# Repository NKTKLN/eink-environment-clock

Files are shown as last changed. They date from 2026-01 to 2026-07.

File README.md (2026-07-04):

# 🖥️ E-Ink Environment Clock





**eink-environment-clock** is a minimal ESP32-C3 based E-Ink desk clock that displays time and indoor air data.
It combines a low-power E-Ink screen with CO₂, temperature, humidity, and pressure sensing, making it useful as both a clock and a compact environment monitor.

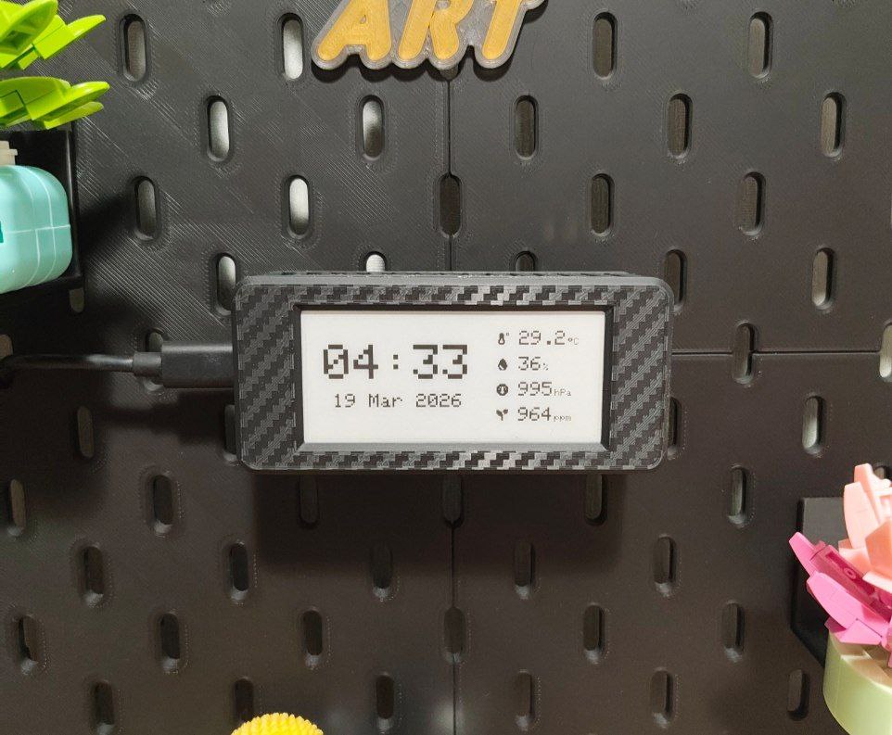
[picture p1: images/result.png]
Result


## 🧩 PCB

PCB design and assembly are illustrated with the following reference images:

```bash
images/
├── assembled_board_image.png
├── circuit_image.png
├── pcb_back_image.png
├── pcb_front_image.png
└── schematic_image.png
```

### Circuit

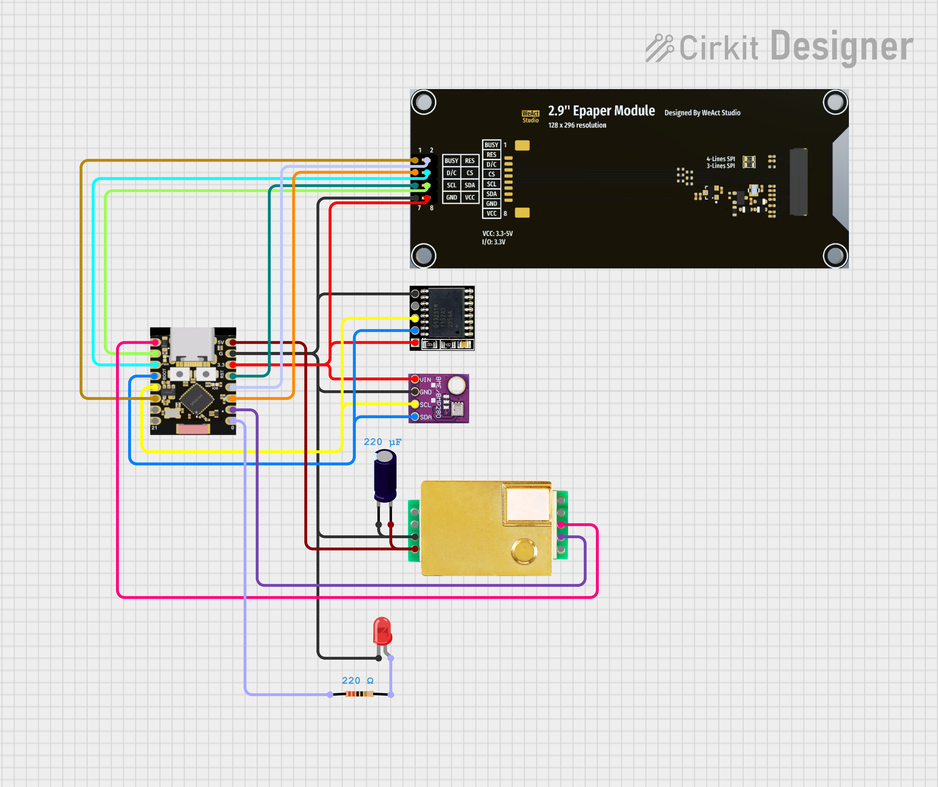
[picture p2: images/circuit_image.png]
Circuit


## 💾 Firmware

The firmware is a pure **ESP-IDF** PlatformIO project (no Arduino) located in:

```bash
firmware/
├── platformio.ini
└── src/
    ├── app_main.c        # application logic
    ├── app_config.h      # pins, Wi-Fi credentials, timings
    ├── secrets.h.example # Wi-Fi credentials template (copy to secrets.h)
    ├── epd_ssd1680.*     # e-paper driver (WeAct 2.9" B/W, SSD1680)
    ├── epd_canvas.*      # 1bpp canvas, bitmap fonts, icons
    ├── ui.*              # clock face rendering
    └── net_time.*        # Wi-Fi + SNTP time sync
```

Before building, set up your Wi-Fi credentials (only needed if `USE_WIFI_TIME_SYNC` is enabled in `app_config.h`):

```bash
cp firmware/src/secrets.h.example firmware/src/secrets.h
# then edit secrets.h with your WIFI_SSID / WIFI_PASSWORD
```

Build and flash (ESP32-C3 Super Mini over native USB):

```bash
cd firmware
pio run -t upload && pio device monitor
```

## 📚 Libraries

Sensors are handled by [esp-idf-lib](https://esp-idf-lib.readthedocs.io/) components (fetched automatically from the ESP Component Registry):

* **bmp280** — BME280 temperature / humidity / pressure
* **ds3231** — RTC
* **mhz19b** — CO₂ sensor

The e-paper driver is custom and follows the panel vendor's reference code from [WeActStudio.EpaperModule](https://github.com/WeActStudio/WeActStudio.EpaperModule).

## 📦 Case

The case model for this project is located in:

```bash
3d_model/
├── stp
│   ├── backplate.stp
│   ├── center.stp
│   └── frontplate.stp
├── case.3mf
└── case.m3d
```

## ⚠️ Known Issues

* Holes for the **MH-Z19** are too small.
* Some modules (**MH-Z19**) are placed too close to the mounting holes, which sometimes makes assembly and fastening inconvenient.

## 📜 License

This project is licensed under the MIT License. See the [LICENSE](./LICENSE) file for details.

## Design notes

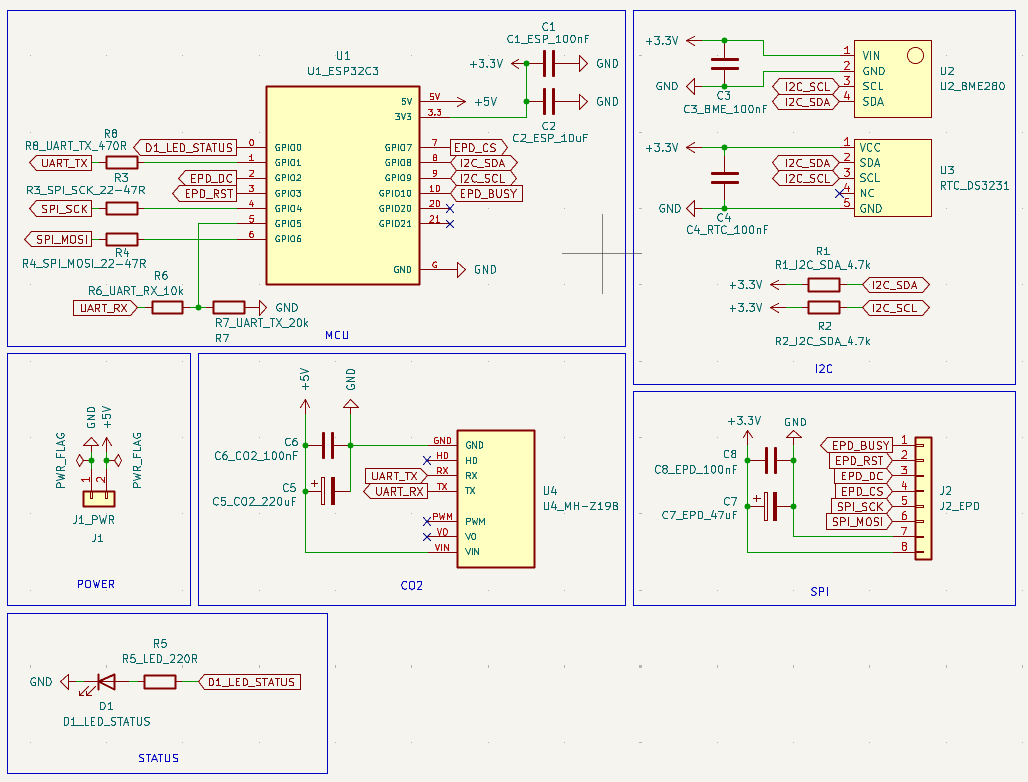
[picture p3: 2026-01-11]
images/schematic_image.png

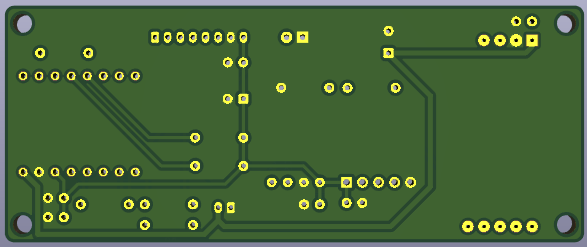
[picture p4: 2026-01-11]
images/pcb_back_image.png

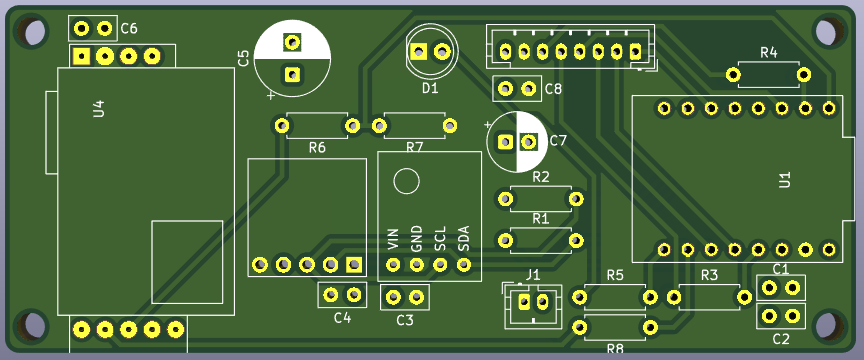
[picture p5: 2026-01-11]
images/pcb_front_image.png

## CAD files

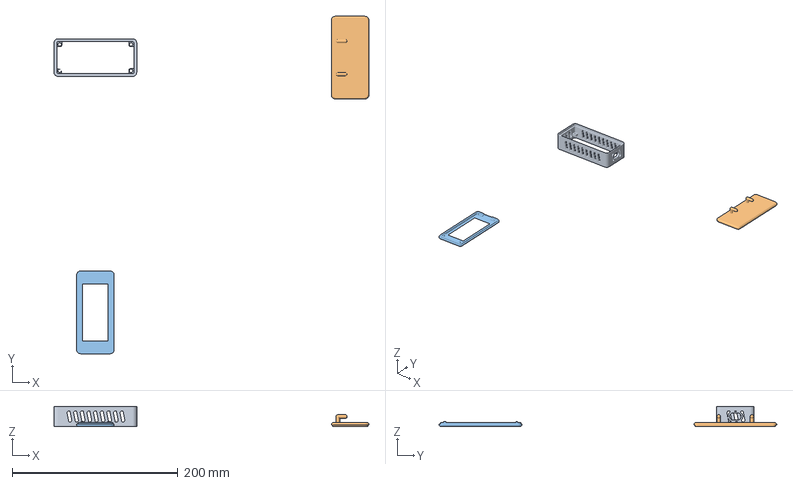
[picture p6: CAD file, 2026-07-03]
3d_model/case.3mf
379.9 x 407.0 x 24.6 mm
frontplate.stp

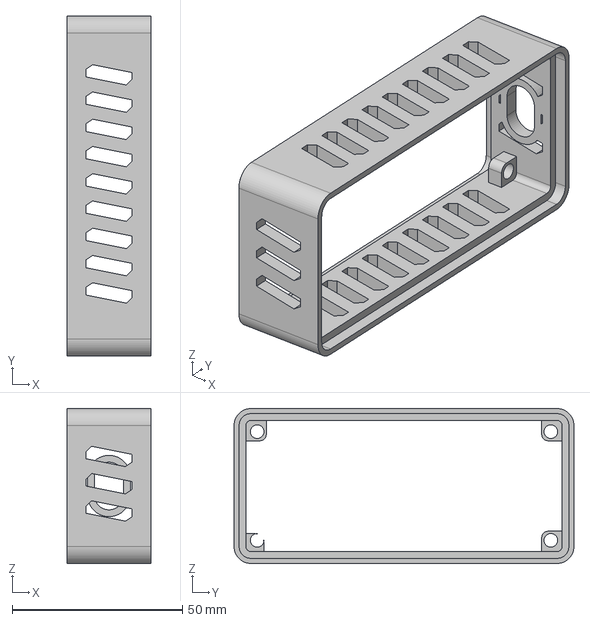
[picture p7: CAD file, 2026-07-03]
3d_model/stp/center.stp
24.6 x 99.8 x 45.5 mm

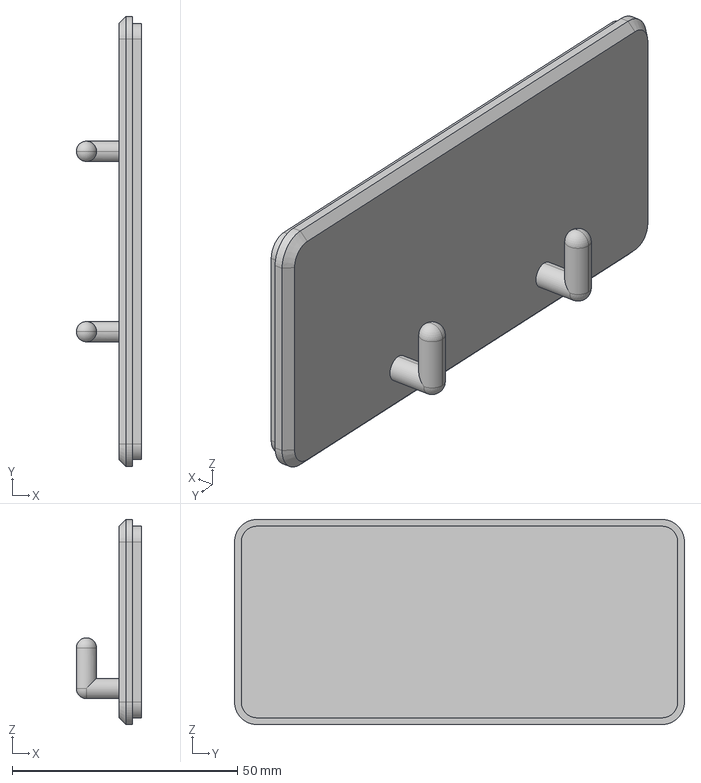
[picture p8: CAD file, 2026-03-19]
3d_model/stp/backplate.stp
14.5 x 99.8 x 45.5 mm

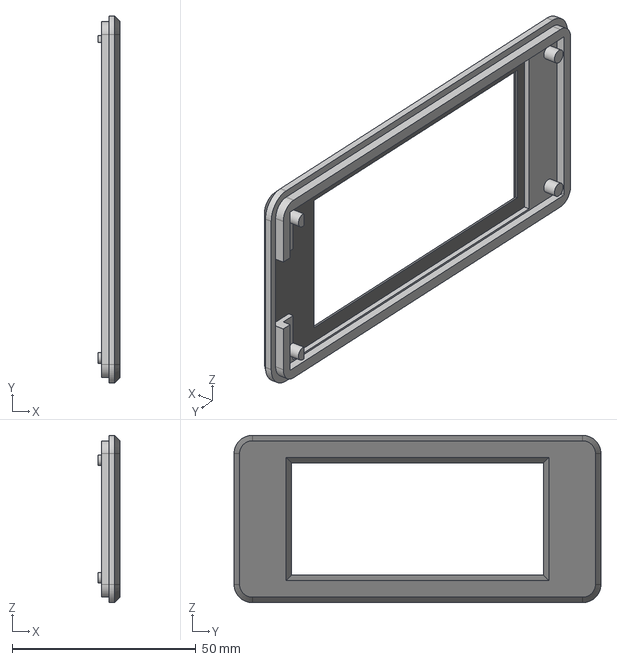
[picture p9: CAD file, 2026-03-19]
3d_model/stp/frontplate.stp
6.00 x 99.8 x 45.5 mm

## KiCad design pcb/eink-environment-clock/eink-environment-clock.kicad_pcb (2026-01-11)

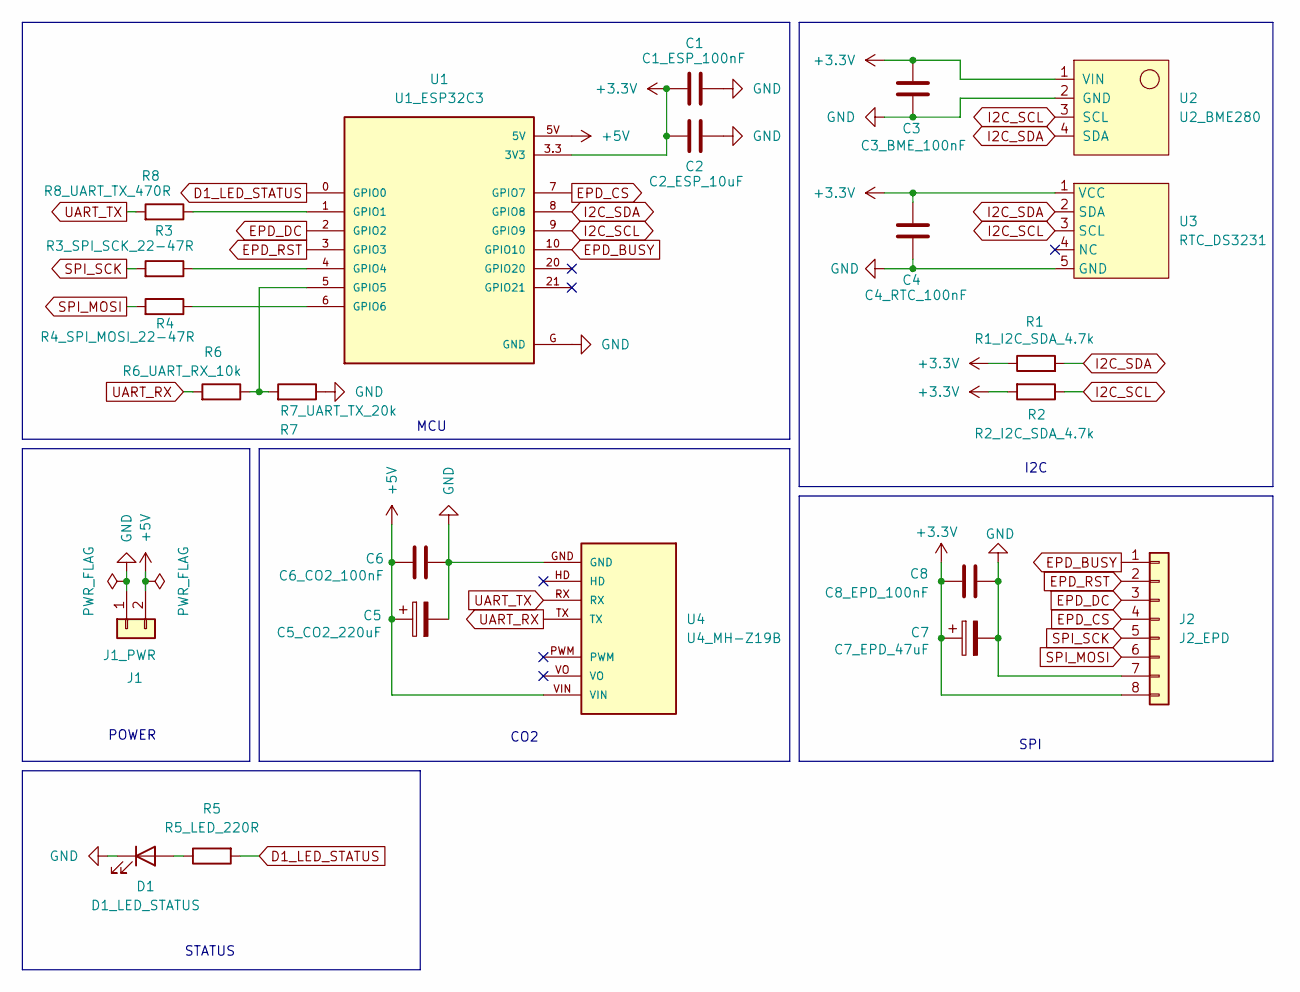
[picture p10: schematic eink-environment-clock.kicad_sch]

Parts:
C1: C1_ESP_100nF; C_Disc_D5.0mm_W2.5mm_P2.50mm
C2: C2_ESP_10uF; C_Disc_D5.0mm_W2.5mm_P2.50mm
C3: C3_BME_100nF; C_Disc_D5.0mm_W2.5mm_P2.50mm
C4: C4_RTC_100nF; C_Disc_D5.0mm_W2.5mm_P2.50mm
C5: C5_CO2_220uF; CP_Radial_D8.0mm_P3.50mm
C6: C6_CO2_100nF; C_Disc_D5.0mm_W2.5mm_P2.50mm
C7: C7_EPD_47uF; CP_Radial_D6.3mm_P2.50mm
C8: C8_EPD_100nF; C_Disc_D5.0mm_W2.5mm_P2.50mm
D1: D1_LED_STATUS; LED_D5.0mm
J1: J1_PWR; JST_PH_B2B-PH-K_1x02_P2.00mm_Vertical
J2: J2_EPD; JST_PH_B8B-PH-K_1x08_P2.00mm_Vertical
R1: R1_I2C_SDA_4.7k; R_Axial_DIN0207_L6.3mm_D2.5mm_P7.62mm_Horizontal
R2: R2_I2C_SDA_4.7k; R_Axial_DIN0207_L6.3mm_D2.5mm_P7.62mm_Horizontal
R3: R3_SPI_SCK_22-47R; R_Axial_DIN0207_L6.3mm_D2.5mm_P7.62mm_Horizontal
R4: R4_SPI_MOSI_22-47R; R_Axial_DIN0207_L6.3mm_D2.5mm_P7.62mm_Horizontal
R5: R5_LED_220R; R_Axial_DIN0207_L6.3mm_D2.5mm_P7.62mm_Horizontal
R6: R6_UART_RX_10k; R_Axial_DIN0207_L6.3mm_D2.5mm_P7.62mm_Horizontal
R7: R7_UART_TX_20k; R_Axial_DIN0207_L6.3mm_D2.5mm_P7.62mm_Horizontal
R8: R8_UART_TX_470R; R_Axial_DIN0207_L6.3mm_D2.5mm_P7.62mm_Horizontal
U1: U1_ESP32C3; MODULE_ESP32-C3_SUPERMINI_TH
U2: U2_BME280; module_bme280_alt
U3: RTC_DS3231; DS3231_For_Pi
U4: U4_MH-Z19B; MH-Z19B

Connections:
+3.3V: C1.2, C2.2, C3.1, C4.1, C7.1, C8.2, J2.8, R1.1, R2.2, U1.3.3 (3V3), U2.1 (VIN), U3.1 (VCC)
+5V: C5.1, C6.2, J1.2, U1.5V, U4.VIN
D1_LED_STATUS: R5.2, U1.0 (GPIO0)
EPD_BUSY: J2.1, U1.10 (GPIO10)
EPD_CS: J2.4, U1.7 (GPIO7)
EPD_DC: J2.3, U1.2 (GPIO2)
EPD_RST: J2.2, U1.3 (GPIO3)
GND: C1.1, C2.1, C3.2, C4.2, C5.2, C6.1, C7.2, C8.1, D1.1 (K), J1.1, J2.7, R7.1, U1.G (GND), U2.2 (GND), U3.5 (GND), U4.GND
I2C_SCL: R2.1, U1.9 (GPIO9), U2.3 (SCL), U3.3 (SCL)
I2C_SDA: R1.2, U1.8 (GPIO8), U2.4 (SDA), U3.2 (SDA)
unnamed: D1.2 (A), R5.1
unnamed: R8.1, U1.1 (GPIO1)
unnamed: R3.1, U1.4 (GPIO4)
unnamed: R6.1, R7.2, U1.5 (GPIO5)
unnamed: R4.1, U1.6 (GPIO6)
SPI_MOSI: J2.6, R4.2
SPI_SCK: J2.5, R3.2
UART_RX: R6.2, U4.TX
UART_TX: R8.2, U4.RX

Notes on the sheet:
POWER
CO2
SPI
I2C
STATUS
MCU

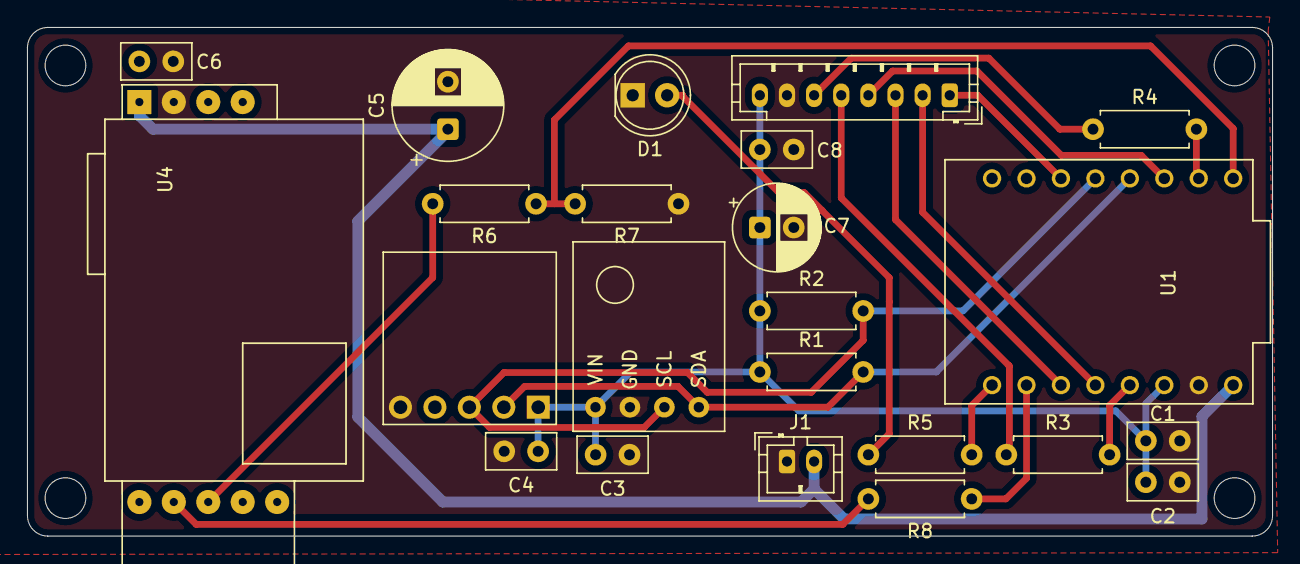
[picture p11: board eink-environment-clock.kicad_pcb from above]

Board: 2 copper layers, 91.8 x 37.5 mm, 23 parts (0 on the bottom side), 19 nets.

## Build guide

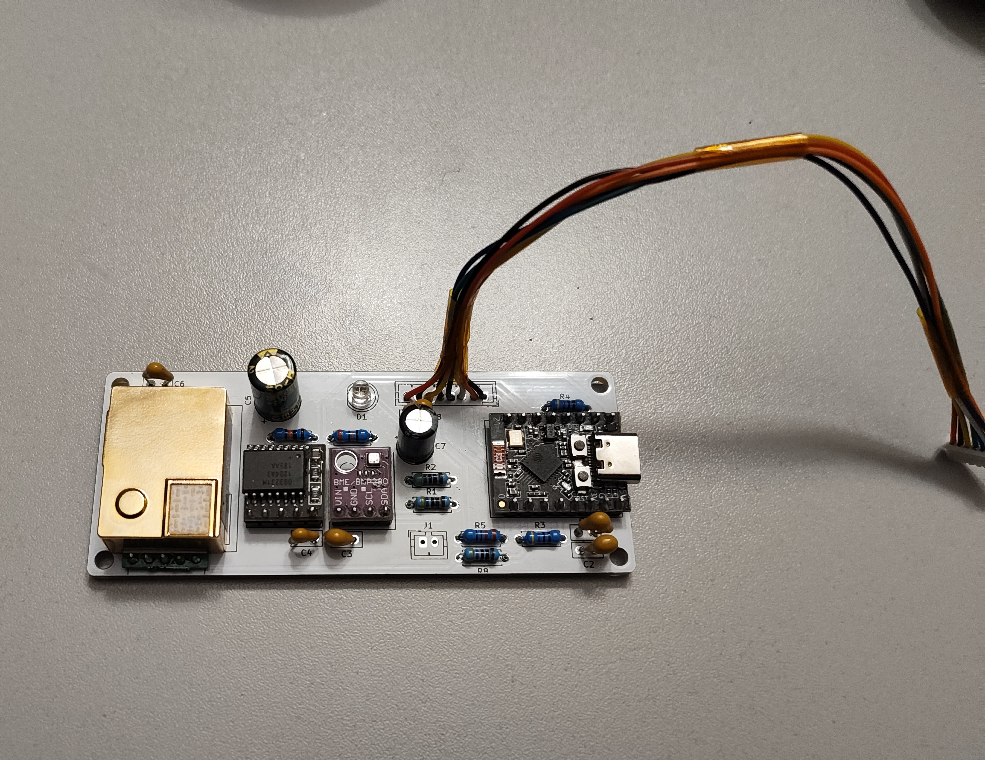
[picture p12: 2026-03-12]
images/assembled_board_image.png

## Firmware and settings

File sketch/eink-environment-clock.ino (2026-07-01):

#include <SPI.h>
#include <GxEPD2_BW.h>
#include <Adafruit_GFX.h>

#include <math.h>
#include <WiFi.h>
#include <Wire.h>
#include <Adafruit_BME280.h>
#include <RTClib.h>
#include <time.h>
#include <MHZ19.h>

// =====================================================
// Pin configuration
// =====================================================

// E-paper display pins
constexpr uint8_t PIN_EPD_DC   = 2;
constexpr uint8_t PIN_EPD_RST  = 3;
constexpr uint8_t PIN_SPI_SCK  = 4;
constexpr uint8_t PIN_SPI_MOSI = 6;
constexpr uint8_t PIN_EPD_CS   = 7;
constexpr uint8_t PIN_EPD_BUSY = 10;

// I2C pins
constexpr uint8_t I2C_SDA_PIN = 8;
constexpr uint8_t I2C_SCL_PIN = 9;

// MH-Z19 UART pins
constexpr uint8_t MHZ_RX_PIN = 5;
constexpr uint8_t MHZ_TX_PIN = 1;

// Status LED pin
constexpr uint8_t LED_PIN = 0;

// =====================================================
// Application configuration
// =====================================================

// Time format
constexpr bool USE_12_HOUR_FORMAT = true;

// Time synchronization
constexpr bool USE_WIFI_TIME_SYNC = true;

// Wi-Fi credentials
constexpr char WIFI_SSID[] = "YourWiFiName";
constexpr char WIFI_PASSWORD[] = "YourWiFiPassword";

// NTP settings
constexpr char NTP_SERVER[] = "pool.ntp.org";
constexpr char TIME_ZONE[]  = "MSK-3";

// BME280 settings
constexpr uint8_t BME280_ADDRESS_PRIMARY   = 0x76;
constexpr uint8_t BME280_ADDRESS_SECONDARY = 0x77;
constexpr float BME280_TEMP_OFFSET_C = -2.3f;

// MZH19b settings
constexpr int CO2_ALERT_THRESHOLD_PPM = 1000;  // Blink the status LED when CO2 exceeds this level

// Screen settings
constexpr bool USE_DARK_THEME = false; // true - not recommended
constexpr bool SKIP_UPDATE_IF_DATA_UNCHANGED = true;

// =====================================================
// Timing configuration
// =====================================================

constexpr uint32_t SENSOR_UPDATE_INTERVAL_MS           = 30000;    // Read sensors every 30 seconds
constexpr uint32_t DISPLAY_UPDATE_INTERVAL_MS          = 1000;     // Update display every second
constexpr uint16_t DISPLAY_FULL_REFRESH_EVERY          = 30;       // Full refresh every N partial updates (clears ghosting)
constexpr uint32_t WIFI_TIME_SYNC_INTERVAL_MS          = 1800000;  // Sync time every 30 minutes
constexpr uint32_t WIFI_CONNECT_TIMEOUT_MS             = 15000;    // Wi-Fi connection timeout
constexpr uint32_t NTP_SYNC_TIMEOUT_MS                 = 15000;    // NTP synchronization timeout
constexpr uint32_t LED_BLINK_INTERVAL_MS               = 1000;     // LED blink interval when CO2 is above the alert threshold

// =====================================================
// Timing state
// =====================================================

uint32_t lastSensorUpdateMs  = 0;
uint32_t lastDisplayUpdateMs = 0;
uint32_t lastTimeSyncMs      = 0;
uint32_t lastLedToggleMs     = 0;

// =====================================================
// Counters
// =====================================================

uint16_t updatesSinceFullRefresh = 0;

// =====================================================
// Runtime flags
// =====================================================

bool wifiConnected     = false;
bool firstDisplayDraw  = true;
bool bme280Available   = false;
bool ds3231Available   = false;
bool mhz19Available    = false;
bool displayAvailable  = false;
bool ledOn             = false;
bool sensorDataChanged = false;
bool timeChanged       = false;

// =====================================================
// Global objects
// =====================================================

// E-paper display driver
GxEPD2_BW<GxEPD2_290_T94_V2, GxEPD2_290_T94_V2::HEIGHT> display(
  GxEPD2_290_T94_V2(PIN_EPD_CS, PIN_EPD_DC, PIN_EPD_RST, PIN_EPD_BUSY)
);

// Peripherals
Adafruit_BME280 bme;
RTC_DS3231 rtc;
MHZ19 mhz19;
HardwareSerial mhzSerial(1);

// =====================================================
// Sensor & time data
// =====================================================

struct SensorData {
  float temperatureC = NAN;
  float humidityPct  = NAN;
  float pressureHpa  = NAN;
  int   co2Ppm       = -1;
};

SensorData lastSensorData;
DateTime lastRtcTime;

// =====================================================
// Bitmap icons
// =====================================================

// 16x16 humidity icon
const unsigned char ICON_DROPLET_16X16[] PROGMEM = {
  0x00, 0x00, 0x00, 0x00, 0x80, 0x01, 0xc0, 0x03, 0xe0, 0x07, 0xe0, 0x07,
  0xf0, 0x0f, 0xf0, 0x0f, 0xf8, 0x1f, 0xd8, 0x1f, 0x98, 0x1f, 0x30, 0x0f,
  0x70, 0x0e, 0xe0, 0x07, 0x00, 0x00, 0x00, 0x00
};

// 16x16 pressure icon
const unsigned char ICON_GAUGE_16X16[] PROGMEM = {
  0x00, 0x00, 0x00, 0x00, 0xe0, 0x07, 0xf0, 0x0f, 0xf8, 0x1f, 0x5c, 0x3a,
  0x7c, 0x3e, 0x6c, 0x36, 0x7c, 0x3e, 0x7c, 0x3e, 0x3c, 0x3c, 0x78, 0x1e,
  0xf0, 0x0f, 0xe0, 0x07, 0x00, 0x00, 0x00, 0x00
};

// 16x16 plant icon
const unsigned char ICON_SEEDLING_16X16[] PROGMEM = {
  0x00, 0x00, 0x00, 0x00, 0x00, 0x3c, 0x1c, 0x3e, 0x7c, 0x3f, 0xfc, 0x3e,
  0xfc, 0x1c, 0xf8, 0x05, 0xf0, 0x01, 0xc0, 0x01, 0x80, 0x01, 0x80, 0x01,
  0x80, 0x01 ,0x80, 0x01, 0x00, 0x00, 0x00, 0x00
};

// 16x16 low temperature icon
const unsigned char ICON_TEMPERATURE_LOW_16X16[] PROGMEM = {
  0x00, 0x00, 0x00, 0x00, 0xe0, 0x38, 0xf0, 0x29, 0xf0, 0x39, 0xf0, 0x01,
  0xf0, 0x01, 0xf0, 0x01, 0xb0, 0x01, 0xb8, 0x03, 0x18, 0x03, 0x18, 0x03,
  0xf8, 0x03, 0xf0, 0x01, 0x00, 0x00, 0x00, 0x00
};

// =====================================================
// Structures
// =====================================================

struct BoxLayout {
  int16_t cursorX;
  int16_t cursorY;
  int16_t boxX;
  int16_t boxY;
  uint16_t boxW;
  uint16_t boxH;
};

// =====================================================
// Data helpers
// =====================================================

bool nearlyEqual(float a, float b, float eps = 0.05f) {
  if (isnan(a) && isnan(b)) return true;
  if (isnan(a) || isnan(b)) return false;
  return fabs(a - b) <= eps;
}

bool isSensorDataSimilar(const SensorData& a, const SensorData& b) {
  return nearlyEqual(a.temperatureC, b.temperatureC, 0.2f) &&
         nearlyEqual(a.humidityPct,  b.humidityPct,  2.0f) &&
         nearlyEqual(a.pressureHpa,  b.pressureHpa,  5.0f) &&
         abs(a.co2Ppm - b.co2Ppm) <= 50;
}

bool hasTimeChanged(const DateTime& a, const DateTime& b) {
  return a.year() != b.year() ||
         a.month() != b.month() ||
         a.day() != b.day() || 
         a.hour() != b.hour() ||
         a.minute() != b.minute();
}

// =====================================================
// Logging
// =====================================================

void logInfo(const char* module, const char* message) {
  Serial.print("[INFO] [");
  Serial.print(module);
  Serial.print("] ");
  Serial.println(message);
}

void logWarn(const char* module, const char* message) {
  Serial.print("[WARN] [");
  Serial.print(module);
  Serial.print("] ");
  Serial.println(message);
}

void logError(const char* module, const char* message) {
  Serial.print("[ERROR] [");
  Serial.print(module);
  Serial.print("] ");
  Serial.println(message);
}

// =====================================================
// Wi-Fi
// =====================================================

bool connectToWifi() {
  if (!USE_WIFI_TIME_SYNC) {
    logWarn("WiFi", "Disabled in configuration.");
    return false;
  }

  WiFi.disconnect(true, true);
  WiFi.mode(WIFI_STA);
  WiFi.begin(WIFI_SSID, WIFI_PASSWORD);

  Serial.print("[INFO] [WiFi] Connecting ");

  const uint32_t startTimeMs = millis();

  while (WiFi.status() != WL_CONNECTED) {
    if (millis() - startTimeMs >= WIFI_CONNECT_TIMEOUT_MS) {
      Serial.println();
      logError("WiFi", "Connection timeout.");
      return false;
    }

    delay(500);
    Serial.print(".");
  }

  Serial.println();
  logInfo("WiFi", "Connected successfully.");
  Serial.print("[INFO] [WiFi] IP: ");
  Serial.println(WiFi.localIP());

  return true;
}

// =====================================================
// Time synchronization
// =====================================================

bool syncTimeFromNtp() {
  if (!wifiConnected) {
    logError("NTP", "Wi-Fi is not connected.");
    return false;
  }

  logInfo("NTP", "Starting synchronization...");

  configTzTime(TIME_ZONE, NTP_SERVER);

  struct tm timeInfo;
  const uint32_t startTimeMs = millis();

  while (!getLocalTime(&timeInfo)) {
    if (millis() - startTimeMs >= NTP_SYNC_TIMEOUT_MS) {
      logError("NTP", "Synchronization timeout.");
      return false;
    }

    delay(200);
  }

  logInfo("NTP", "Time synchronized successfully.");
  return true;
}

bool syncRtcFromNtp() {
  if (!ds3231Available) {
    logError("DS3231", "RTC is not available.");
    return false;
  }

  if (!syncTimeFromNtp()) {
    return false;
  }

  struct tm timeInfo;
  if (!getLocalTime(&timeInfo)) {
    logError("DS3231", "Failed to read synchronized time.");
    return false;
  }

  rtc.adjust(DateTime(
    timeInfo.tm_year + 1900,
    timeInfo.tm_mon + 1,
    timeInfo.tm_mday,
    timeInfo.tm_hour,
    timeInfo.tm_min,
    timeInfo.tm_sec
  ));

  logInfo("DS3231", "Time synced from NTP.");
  return true;
}

bool syncRtcFromCompileTime() {
  if (!ds3231Available) {
    logError("DS3231", "RTC is not available.");
    return false;
  }

  rtc.adjust(DateTime(F(__DATE__), F(__TIME__)));
  logInfo("DS3231", "Time synced from compile time.");
  return true;
}

// =====================================================
// Initialization
// =====================================================

bool initBme280() {
  if (bme.begin(BME280_ADDRESS_PRIMARY) || bme.begin(BME280_ADDRESS_SECONDARY)) {
    bme.setSampling(
      Adafruit_BME280::MODE_FORCED,
      Adafruit_BME280::SAMPLING_X1,
      Adafruit_BME280::SAMPLING_X1,
      Adafruit_BME280::SAMPLING_X1,
      Adafruit_BME280::FILTER_OFF
    );

    logInfo("BME280", "Initialized.");
    return true;
  }

  logError("BME280", "Initialization failed.");
  return false;
}

bool initMhz19() {
  mhzSerial.begin(9600, SERIAL_8N1, MHZ_RX_PIN, MHZ_TX_PIN);
  mhz19.begin(mhzSerial);
  mhz19.autoCalibration(false);

  logInfo("MH-Z19", "UART started.");
  logInfo("MH-Z19", "Warm-up may take a few minutes.");
  return true;
}

bool initRtc() {
  if (rtc.begin()) {
    logInfo("DS3231", "Initialized.");
    return true;
  }
  
  logError("DS3231", "Initialization failed.");
  return false;
}

bool initEpd() {
  pinMode(PIN_EPD_BUSY, INPUT);
  SPI.begin(PIN_SPI_SCK, -1, PIN_SPI_MOSI, PIN_EPD_CS);

  logInfo("EPD", "Initializing...");

  display.init(115200);
  display.setRotation(3);

  display.clearScreen();

  logInfo("EPD", "Initialized.");
  return true;
}

void initLed() {
  pinMode(LED_PIN, OUTPUT);
  digitalWrite(LED_PIN, LOW);
  logInfo("Led", "Initialized.");
}

// =====================================================
// Sensor handling
// =====================================================

void readSensors() {
  SensorData newData = lastSensorData;

  if (bme280Available) {
    bme.takeForcedMeasurement();
    
    const float temperatureC = bme.readTemperature() + BME280_TEMP_OFFSET_C;
    const float humidityPct  = bme.readHumidity();
    const float pressureHpa  = bme.readPressure() / 100.0F;

    if (!isnan(temperatureC)) newData.temperatureC = temperatureC;
    if (!isnan(humidityPct)) newData.humidityPct = humidityPct;
    if (!isnan(pressureHpa)) newData.pressureHpa = pressureHpa;
  }

  if (mhz19Available) {
    const int co2Ppm = mhz19.getCO2();

    if (co2Ppm > 0 && co2Ppm <= 10000) newData.co2Ppm = co2Ppm;
  }

  if (!isSensorDataSimilar(lastSensorData, newData)) {
    lastSensorData = newData;
    sensorDataChanged = true;
  }
}

void readCurrentTime() {
  if (!ds3231Available) return;

  const DateTime now = rtc.now();

  if (hasTimeChanged(now, lastRtcTime)) {
    lastRtcTime = now;
    timeChanged = true;
  }
}

// =====================================================
// Serial data log
// =====================================================

void printCurrentTime() {
  if (!ds3231Available) {
    return;
  }

  const DateTime now = rtc.now();

  char buffer[32];
  snprintf(
    buffer,
    sizeof(buffer),
    "%02u.%02u.%04u %02u:%02u:%02u",
    now.day(),
    now.month(),
    now.year(),
    now.hour(),
    now.minute(),
    now.second()
  );

  Serial.print("[INFO] [RTC] ");
  Serial.println(buffer);
}

void printSensorData() {
  if (bme280Available) {
    Serial.print("[INFO] [BME280] T=");
    Serial.print(lastSensorData.temperatureC, 1);
    Serial.print(" C, H=");
    Serial.print(lastSensorData.humidityPct, 0);
    Serial.print(" %, P=");
    Serial.print(lastSensorData.pressureHpa, 0);
    Serial.println(" hPa");
  }

  if (mhz19Available && lastSensorData.co2Ppm > 0) {
    Serial.print("[INFO] [MH-Z19] CO2=");
    Serial.print(lastSensorData.co2Ppm);
    Serial.println(" ppm");
  }
}

void printFullData() {
  printCurrentTime();
  printSensorData();
}

// =====================================================
// LED handling
// =====================================================

void updateCo2Led() {
  if (lastSensorData.co2Ppm > CO2_ALERT_THRESHOLD_PPM) {
    const uint32_t nowMs = millis(); 

    if (nowMs - lastLedToggleMs >= LED_BLINK_INTERVAL_MS) {
      lastLedToggleMs = nowMs;
      ledOn = !ledOn;
      digitalWrite(LED_PIN, ledOn ? HIGH : LOW);
    }
  } else {
    ledOn = false;
    digitalWrite(LED_PIN, LOW);
  }
}

// =====================================================
// Display helpers
// =====================================================

uint16_t getThemeBackgroundColor() {
  return USE_DARK_THEME ? GxEPD_BLACK : GxEPD_WHITE;
}

uint16_t getThemeForegroundColor() {
  return USE_DARK_THEME ? GxEPD_WHITE : GxEPD_BLACK;
}

void formatDisplayDate(char* buffer, size_t size) {
  static const char* MONTHS[] = {
    "Jan", "Feb", "Mar", "Apr", "May", "Jun",
    "Jul", "Aug", "Sep", "Oct", "Nov", "Dec"
  };

  if (!ds3231Available) {
    snprintf(buffer, size, "--.--.----");
    return;
  }

  snprintf(
    buffer,
    size,
    "%u %s %u",
    lastRtcTime.day(),
    MONTHS[lastRtcTime.month() - 1],
    lastRtcTime.year()
  );
}

void formatDisplayTime(char* buffer, size_t size) {
  if (!ds3231Available) {
    snprintf(buffer, size, "--:--");
    return;
  }

  uint8_t hour = lastRtcTime.hour();

  if (USE_12_HOUR_FORMAT) {
    hour %= 12;
    if (hour == 0) {
      hour = 12;
    }
  }

  snprintf(buffer, size, "%02u:%02u", hour, lastRtcTime.minute());
}

// =====================================================
// Display render
// =====================================================

void drawCenteredText(const char* text, int16_t baselineY, uint8_t textSize, uint16_t areaWidth) {
  display.setFont();
  display.setTextSize(textSize);

  int16_t x1, y1;
  uint16_t w, h;
  display.getTextBounds(text, 0, 0, &x1, &y1, &w, &h);

  int16_t x = (areaWidth - (int16_t)w) / 2 - x1;
  int16_t y = baselineY;

  display.getTextBounds(text, x, y, &x1, &y1, &w, &h);

  display.setCursor(x, y);
  display.print(text);
}

void drawFloatMetric(int16_t iconX, int16_t topY, const unsigned char* icon, float value, uint8_t decimals, const char* unit) {
  const uint16_t fg = getThemeForegroundColor();

  char valueText[16];
  if (isnan(value)) {
    snprintf(valueText, sizeof(valueText), "---");
  } else {
    snprintf(valueText, sizeof(valueText), "%.*f", decimals, value);
  }

  display.drawXBitmap(iconX, topY, icon, 16, 16, fg);

  display.setTextSize(2);
  display.setCursor(iconX + 24, topY);
  display.print(valueText);

  if (unit != nullptr && unit[0] != '\0') {
    const int16_t cursorX = display.getCursorX();
    display.setTextSize(1);
    display.setCursor(cursorX + 1, topY + 6);
    display.print(unit);
  }
}

void drawPartialRegion(int16_t x, int16_t y, int16_t w, int16_t h, void (*drawContent)()) {
  const uint16_t bg = getThemeBackgroundColor();
  const uint16_t fg = getThemeForegroundColor();

  display.setPartialWindow(x, y, w, h);
  display.firstPage();
  do {
    display.fillRect(x, y, w, h, bg);
    display.setTextColor(fg);
    display.setFont();
    drawContent();
  } while (display.nextPage());
}

// =====================================================
// Display UI
// =====================================================
void drawTimeRegion() {
  char dateBuffer[20];
  char timeBuffer[16];

  formatDisplayDate(dateBuffer, sizeof(dateBuffer));
  formatDisplayTime(timeBuffer, sizeof(timeBuffer));

  drawCenteredText(timeBuffer, 31, 5, 185);
  drawCenteredText(dateBuffer, 81, 2, 185);
}

void drawSensorRegion() {
  drawFloatMetric(190, 17, ICON_TEMPERATURE_LOW_16X16, lastSensorData.temperatureC, 1, "\xF7""C");
  drawFloatMetric(190, 43, ICON_DROPLET_16X16,         lastSensorData.humidityPct,  0, "%");
  drawFloatMetric(190, 69, ICON_GAUGE_16X16,           lastSensorData.pressureHpa,  0, "hPa");
  drawFloatMetric(190, 95, ICON_SEEDLING_16X16,        lastSensorData.co2Ppm,       0, "ppm");
}

void drawFullScreen() {
  const uint16_t bg = getThemeBackgroundColor();
  const uint16_t fg = getThemeForegroundColor();

  display.setFullWindow();
  display.firstPage();
  do {
    display.fillScreen(bg);
    display.setTextColor(fg);
    display.setFont();
    
    drawTimeRegion();
    drawSensorRegion();
  } while (display.nextPage());
}

void drawPartialScreen() {
  bool didPartial = false;

  if (timeChanged || !SKIP_UPDATE_IF_DATA_UNCHANGED) {
    drawPartialRegion(13, 24, 158, 80, drawTimeRegion);
    timeChanged = false;
    didPartial = true;
  }

  if (sensorDataChanged || !SKIP_UPDATE_IF_DATA_UNCHANGED) {
    drawPartialRegion(186, 8, 110, 112, drawSensorRegion);
    sensorDataChanged = false;
    didPartial = true;
  }

  if (didPartial) ++updatesSinceFullRefresh;
}

void drawDisplay() {
  if (firstDisplayDraw || (updatesSinceFullRefresh >= DISPLAY_FULL_REFRESH_EVERY)) {
    drawFullScreen();
    updatesSinceFullRefresh = 0;
    timeChanged = false;
    sensorDataChanged = false;
    firstDisplayDraw = false;
  }
  
  drawPartialScreen();
  firstDisplayDraw = false;
}

// =====================================================
// Setup
// =====================================================

void setup() {
  Serial.begin(115200);
  delay(1500);

  Wire.begin(I2C_SDA_PIN, I2C_SCL_PIN);

  wifiConnected    = connectToWifi();
  bme280Available  = initBme280();
  mhz19Available   = initMhz19();
  ds3231Available  = initRtc();
  displayAvailable = initEpd();
  initLed();

  if (!syncRtcFromNtp()) {
    syncRtcFromCompileTime();
  }
}

// =====================================================
// Loop
// =====================================================

void loop() {
  const uint32_t nowMs = millis();

  if (USE_WIFI_TIME_SYNC && !wifiConnected) {
    wifiConnected = connectToWifi();
  }

  readCurrentTime();

  if (nowMs - lastSensorUpdateMs >= SENSOR_UPDATE_INTERVAL_MS) {
    lastSensorUpdateMs = nowMs;
    readSensors();
  }

  if (nowMs - lastDisplayUpdateMs >= DISPLAY_UPDATE_INTERVAL_MS) {
    lastDisplayUpdateMs = nowMs;
    drawDisplay();
    printFullData();
  }

  updateCo2Led();

  if (USE_WIFI_TIME_SYNC && wifiConnected &&
      nowMs - lastTimeSyncMs >= WIFI_TIME_SYNC_INTERVAL_MS) {
    lastTimeSyncMs = nowMs;
    syncRtcFromNtp();
  }
}

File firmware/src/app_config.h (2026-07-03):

#pragma once

#include <stdbool.h>
#include <stdint.h>

/* =====================================================
 * Pin configuration (ESP32-C3 Super Mini)
 * ===================================================== */

/* E-paper display (SPI) */
#define PIN_EPD_DC   2
#define PIN_EPD_RST  3
#define PIN_SPI_SCK  4
#define PIN_SPI_MOSI 6
#define PIN_EPD_CS   7
#define PIN_EPD_BUSY 10

/* I2C bus (BME280 + DS3231) */
#define PIN_I2C_SDA 8
#define PIN_I2C_SCL 9

/* MH-Z19 UART (ESP RX <- sensor TX, ESP TX -> sensor RX) */
#define PIN_MHZ_RX 5
#define PIN_MHZ_TX 1

/* Status LED */
#define PIN_LED 0

/* =====================================================
 * Application configuration
 * ===================================================== */

#define USE_12_HOUR_FORMAT true

#define USE_WIFI_TIME_SYNC true
#include "secrets.h" /* defines WIFI_SSID / WIFI_PASSWORD, not tracked by git */

#define NTP_SERVER "pool.ntp.org"
#define TIME_ZONE  "MSK-3" /* POSIX TZ string */

/* BME280 */
#define BME280_TEMP_OFFSET_C (-2.3f)

/* MH-Z19 */
#define CO2_ALERT_THRESHOLD_PPM 1000

/* =====================================================
 * Timing configuration
 * ===================================================== */

#define SENSOR_UPDATE_INTERVAL_S   30   /* Read sensors every 30 seconds */
#define TIME_SYNC_INTERVAL_S       1800 /* SNTP resync every 30 minutes */

/* Display refresh policy (anti-ghosting):
 *  - full (flashing) refresh on boot;
 *  - differential (partial) refresh when the displayed data changes,
 *    but not more often than once in DISPLAY_MIN_UPDATE_PERIOD_S;
 *  - forced full refresh after DISPLAY_FULL_REFRESH_EVERY_N partials. */
#define DISPLAY_MIN_UPDATE_PERIOD_S   10
#define DISPLAY_FULL_REFRESH_EVERY_N  10

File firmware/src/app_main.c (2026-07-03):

#include <math.h>
#include <string.h>
#include <time.h>

#include "freertos/FreeRTOS.h"
#include "freertos/task.h"

#include "driver/gpio.h"
#include "esp_heap_caps.h"
#include "esp_log.h"
#include "esp_timer.h"

#include <bmp280.h>
#include <ds3231.h>
#include <i2cdev.h>
#include <mhz19b.h>

#include "app_config.h"
#include "epd_ssd1680.h"
#include "net_time.h"
#include "ui.h"

static const char *TAG = "app";

static bmp280_t s_bme;
static i2c_dev_t s_rtc;
static mhz19b_dev_t s_mhz;

static bool s_bme_ok;
static bool s_rtc_ok;
static bool s_mhz_ok;

static uint8_t *s_fb;

/* ===================================================== */

static void init_bme280(void)
{
    const uint8_t addrs[] = { BMP280_I2C_ADDRESS_0, BMP280_I2C_ADDRESS_1 };

    bmp280_params_t params;
    bmp280_init_default_params(&params);

    for (size_t i = 0; i < sizeof(addrs); i++) {
        memset(&s_bme, 0, sizeof(s_bme));
        ESP_ERROR_CHECK(bmp280_init_desc(&s_bme, addrs[i], I2C_NUM_0,
                                         PIN_I2C_SDA, PIN_I2C_SCL));
        if (bmp280_init(&s_bme, &params) == ESP_OK) {
            s_bme_ok = true;
            ESP_LOGI(TAG, "BME280 found at 0x%02X (chip id 0x%02X)",
                     addrs[i], s_bme.id);
            return;
        }
        bmp280_free_desc(&s_bme);
    }
    ESP_LOGE(TAG, "BME280 not found");
}

static void init_ds3231(void)
{
    memset(&s_rtc, 0, sizeof(s_rtc));
    ESP_ERROR_CHECK(ds3231_init_desc(&s_rtc, I2C_NUM_0,
                                     PIN_I2C_SDA, PIN_I2C_SCL));

    struct tm probe;
    s_rtc_ok = ds3231_get_time(&s_rtc, &probe) == ESP_OK;
    if (s_rtc_ok) {
        ESP_LOGI(TAG, "DS3231 initialized");
    } else {
        ESP_LOGE(TAG, "DS3231 not found");
    }
}

static void init_mhz19(void)
{
    s_mhz_ok = mhz19b_init(&s_mhz, UART_NUM_1, PIN_MHZ_TX, PIN_MHZ_RX) == ESP_OK;
    if (!s_mhz_ok) {
        ESP_LOGE(TAG, "MH-Z19 UART init failed");
        return;
    }
    /* The sensor lives indoors: automatic baseline calibration off. */
    mhz19b_set_auto_calibration(&s_mhz, false);
    ESP_LOGI(TAG, "MH-Z19 initialized (warm-up takes up to 3 minutes)");
}

/* ===================================================== */

static bool get_current_time(struct tm *out)
{
    if (s_rtc_ok && ds3231_get_time(&s_rtc, out) == ESP_OK &&
        out->tm_year >= 120) {
        return true;
    }

    /* Fall back to system time (valid once SNTP has synced). */
    time_t t = time(NULL);
    localtime_r(&t, out);
    return out->tm_year >= 120;
}

static void sync_rtc_from_system_time(void)
{
    if (!s_rtc_ok) {
        return;
    }

    time_t t = time(NULL);
    struct tm now;
    localtime_r(&t, &now); /* the RTC keeps local time */

    if (ds3231_set_time(&s_rtc, &now) == ESP_OK) {
        ESP_LOGI(TAG, "DS3231 synced from NTP time");
    } else {
        ESP_LOGE(TAG, "DS3231 write failed");
    }
}

static void read_sensors(sensor_data_t *data)
{
    if (s_bme_ok) {
        float t, p, h;
        if (bmp280_read_float(&s_bme, &t, &p, &h) == ESP_OK) {
            data->temperature_c = t + BME280_TEMP_OFFSET_C;
            data->pressure_hpa = p / 100.0f;
            if (s_bme.id == BME280_CHIP_ID) {
                data->humidity_pct = h;
            }
        }
    }

    if (s_mhz_ok) {
        int16_t co2 = 0;
        if (mhz19b_read_co2(&s_mhz, &co2) == ESP_OK && co2 > 0) {
            data->co2_ppm = co2;
        }
    }

    ESP_LOGI(TAG, "T=%.1f C, H=%.0f %%, P=%.0f hPa, CO2=%d ppm",
             data->temperature_c, data->humidity_pct, data->pressure_hpa,
             data->co2_ppm);
}

static bool nearly_equal(float a, float b, float eps)
{
    if (isnan(a) && isnan(b)) {
        return true;
    }
    if (isnan(a) || isnan(b)) {
        return false;
    }
    return fabsf(a - b) <= eps;
}

/* True when the difference would not be visible on the display anyway. */
static bool sensor_data_similar(const sensor_data_t *a, const sensor_data_t *b)
{
    return nearly_equal(a->temperature_c, b->temperature_c, 0.2f) &&
           nearly_equal(a->humidity_pct, b->humidity_pct, 2.0f) &&
           nearly_equal(a->pressure_hpa, b->pressure_hpa, 2.0f) &&
           abs(a->co2_ppm - b->co2_ppm) <= 50;
}

static int minute_key(const struct tm *t)
{
    return (((t->tm_year * 12 + t->tm_mon) * 31 + t->tm_mday) * 24 +
            t->tm_hour) * 60 + t->tm_min;
}

static void update_co2_led(int co2_ppm)
{
    static bool led_on;

    if (co2_ppm > CO2_ALERT_THRESHOLD_PPM) {
        led_on = !led_on;
    } else {
        led_on = false;
    }
    gpio_set_level(PIN_LED, led_on);
}

/* ===================================================== */
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

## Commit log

2026-01-01 feat (cirkit image): Add the first version of the connection schematic
2026-01-01 feat(cirkit-image): Add an electrolytic capacitor to the MH-Z19B for stable working
2026-01-02 style(cirkit-image): Update connection schematic
2026-01-11 feat(pcb): Add pcb
    [eink-environment-clock-B_Cu.gbr, eink-environment-clock-B_Mask.gbr, eink-environment-clock-B_Paste.gbr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]
2026-01-11 feat(pcb): Add images and update R8
    [eink-environment-clock.kicad_pcb, eink-environment-clock.kicad_sch]
2026-03-12 docs(readme): update README
    Added PCB design reference images and updated layout.
2026-03-13 feat(sketch): Add CO2 LED alert
    Updated Wi-Fi credentials and added LED handling for CO2 alert. Adjusted sensor update interval and display text positioning.
2026-03-14 ui(sketch): Fix data row cords
    [eink-environment-clock.ino]
2026-03-19 feat(case): Add case model
    [backplate.stp, case.3mf, center.stp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]
2026-03-19 docs(README.md): Update PCB paragraph
2026-03-19 fix(case): New version (more durable)
    [backplate.stp, case.3mf, center.stp]
2026-03-26 fix(sensor-display): skip e-paper refresh when data and time are unchanged
    [eink-environment-clock.ino]
2026-03-26 feat(sketch): Add a flag to skip the display refresh
    [eink-environment-clock.ino]
2026-04-02 reafactor(sketch): Refactor sensor and display update logic
2026-04-03 fix(sketch): update logic and timing intervals
    [eink-environment-clock.ino]
2026-07-01 fix(sketch): trying to fix ghosting
    [eink-environment-clock.ino]
2026-07-03 chore(sketch): move arduino sketch into nested sketch folder
2026-07-03 feat(firmware): scaffold esp-idf platformio project for esp32-c3 super mini
2026-07-03 feat(firmware): add ssd1680 e-paper driver with anti-ghosting refresh policy
    Full refresh writes both controller RAM planes so differential updates
    diff against a correct base; partial refresh re-syncs the previous-image
    RAM and floats the border to avoid greying; the panel deep-sleeps
    between refreshes. Sequences follow the WeAct/vendor reference code for
    the YRD0290BBS800F6HP panel (DEPG0290BS, SSD1680).
    [epd_ssd1680.c]
2026-07-03 feat(firmware): add 1bpp canvas with bitmap fonts and icons
    Fonts come from the WeAct Studio EpaperModule example; icons are
    carried over from the arduino sketch.
2026-07-03 feat(firmware): add clock ui and application logic
    Sensors are handled by esp-idf-lib components (bmp280, ds3231, mhz19b).
    The display updates only when visible data changes, with a forced full
    refresh every 30 partial updates to keep the panel clean.
2026-07-03 chore!: remove legacy arduino sketch superseded by esp-idf firmware
2026-07-03 feat(firmware): restore classic 5x7 font from the arduino version
    Replace the WeAct bitmap fonts with the Adafruit-GFX classic 5x7 font
    scaled by integer factors, and mirror the original sketch layout.
2026-07-03 fix(ui): shift clock and sensor blocks ~20px down, tighten sensor rows
2026-07-03 fix(display): map source outputs from S8 to correct 8px panel shift
    The DEPG0290BS glass sits at S8..S135 of the SSD1680; without 0x21=0x80
    the image was shifted up by 8 pixels with a blank stripe at the bottom.
    [epd_ssd1680.c]
2026-07-03 fix(ui): final vertical alignment of clock and sensor blocks
2026-07-03 feat(case): update case design
    [case.3mf, center.stp]
2026-11-03 feat(web): add web interface with display editor and setup flow
2026-11-03 fix(firmware): raise socket and stack limits, delay restarts past refresh
2026-11-03 style(web): tone down buttons in the dark theme
2026-11-03 style(web): replace native controls and tighten footer spacing
2026-11-03 feat(logs): keep recent device log in ram
2026-11-04 ci(release): attach firmware.bin from a non-hidden directory
2026-11-04 perf(wifi): disable modem sleep to stop stalled page loads
2026-11-05 fix(web): wait up to 30s and allow more open sockets
